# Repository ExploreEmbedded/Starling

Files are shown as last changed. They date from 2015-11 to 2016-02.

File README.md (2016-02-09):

# Starling

Starling is live on CrowdSupply, back us and help this open-source project get to life :)

https://www.crowdsupply.com/explore-embedded/starling 

Starling, aims to be a modular Wifi connected hackable LED Display board. It can be used out of the box to display text messages and custom characters. It can be used from anywhere you're. It should also be able to expand and display messages from web; sports, schedules, social network notifications, whether data, news and anything else you want. The display should be able to expand without changes in the software. The display blocks can be added or removed on the fly 

Front view

For more details do visit the product wiki page.

http://exploreembedded.com/wiki/Starling:_A_simple_internet_connected_modular_led_display.

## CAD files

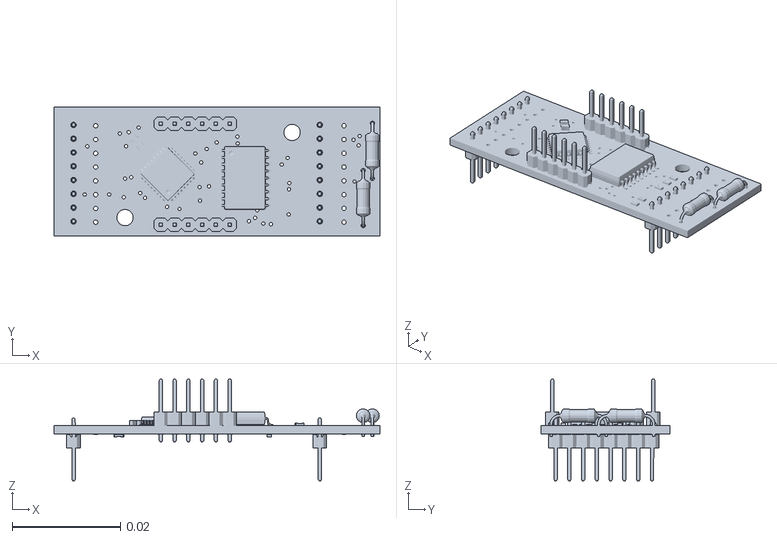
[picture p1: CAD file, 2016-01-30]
Electronics/Starling Matrix PCB v0.2/Starling_V1.stl
0.0601 x 0.0238 x 0.0188

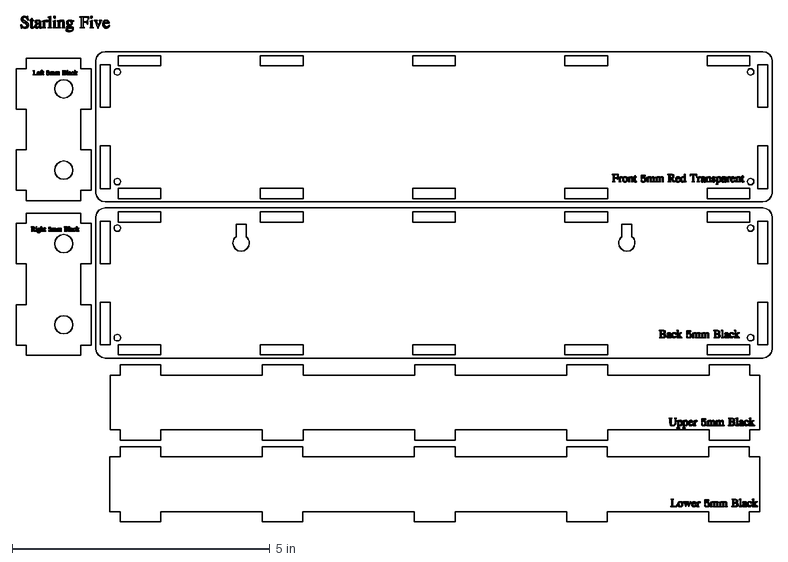
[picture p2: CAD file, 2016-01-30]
Mechanical Design/Starling Five/Starling Five.dxf
14.7 x 9.80 in

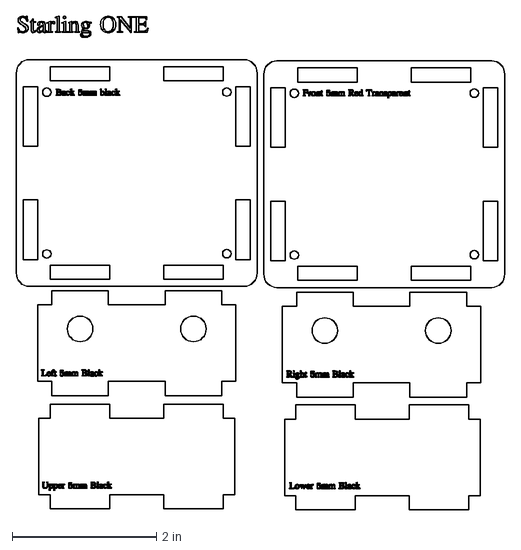
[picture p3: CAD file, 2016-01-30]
Mechanical Design/Starling ONE/Starling ONE.dxf
6.78 x 6.86 in

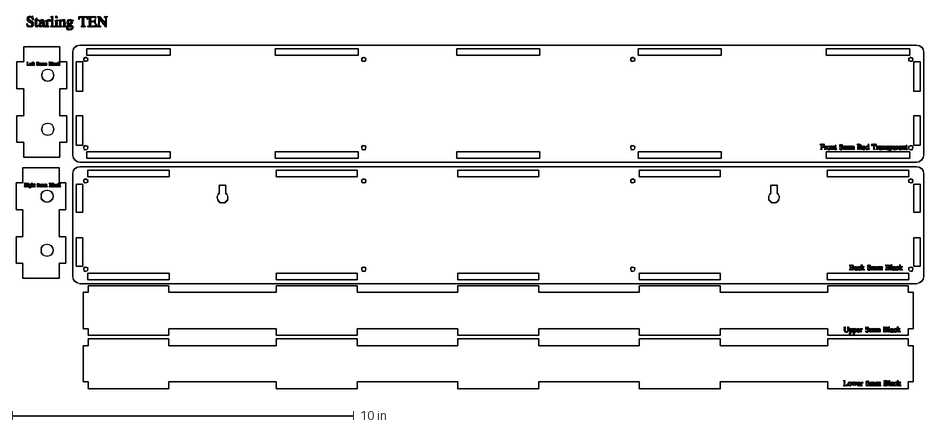
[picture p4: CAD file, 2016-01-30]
Mechanical Design/Starling TEN/Starling TEN.dxf
26.6 x 10.9 in

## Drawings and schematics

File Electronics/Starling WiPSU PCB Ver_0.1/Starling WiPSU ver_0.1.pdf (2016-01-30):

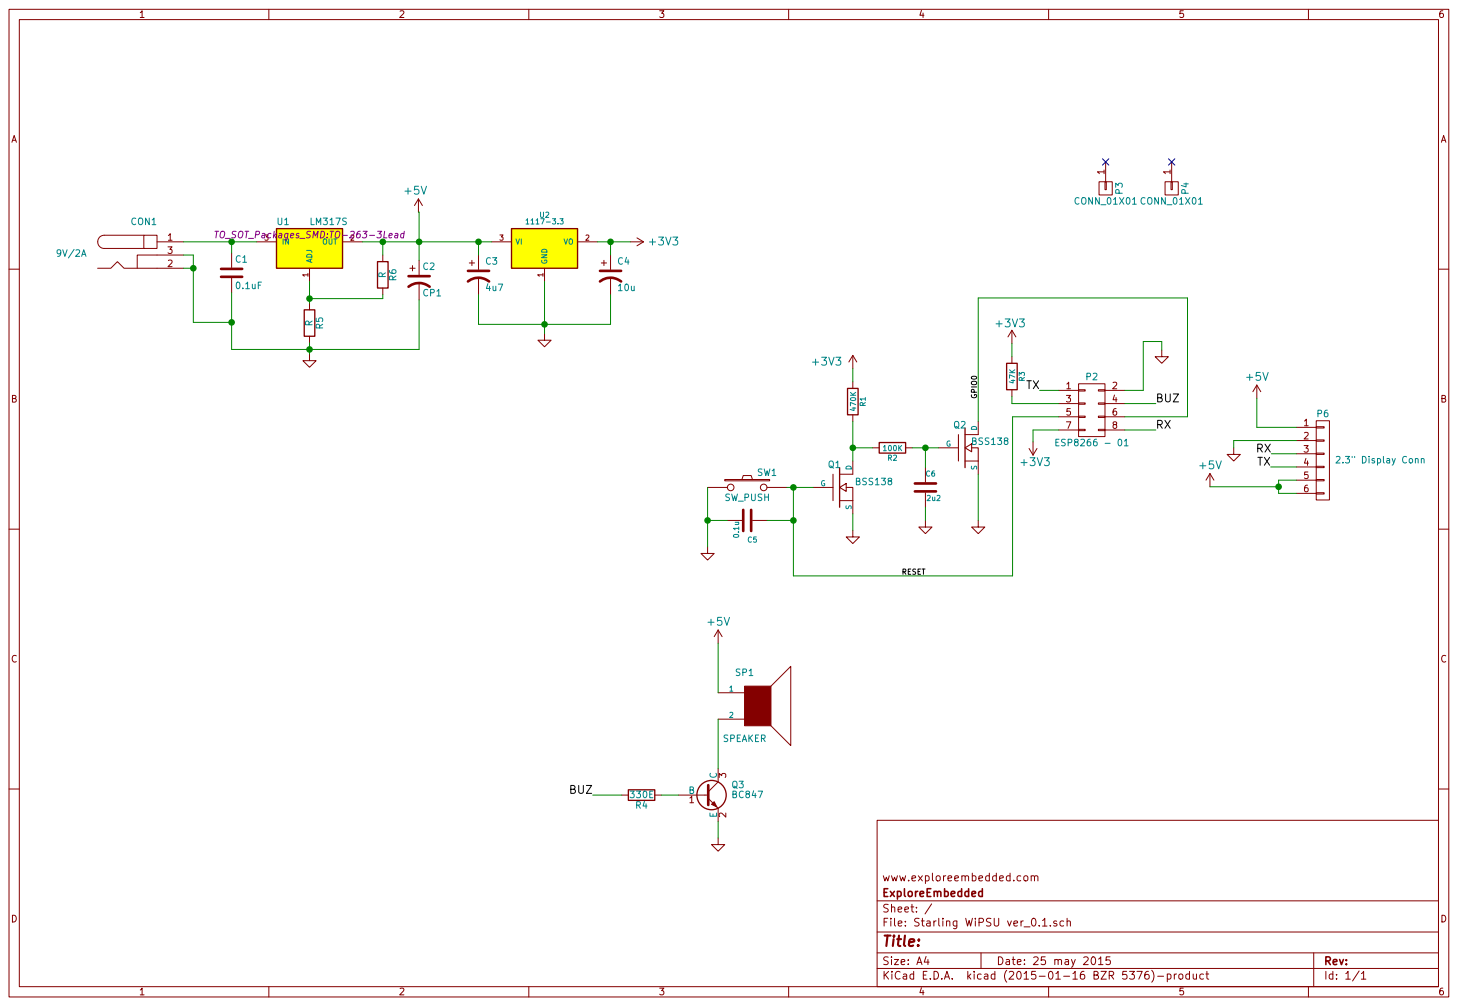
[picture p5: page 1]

www.exploreembedded.com
File: Starling WiPSU ver_0.1.sch Sheet: / ExploreEmbedded

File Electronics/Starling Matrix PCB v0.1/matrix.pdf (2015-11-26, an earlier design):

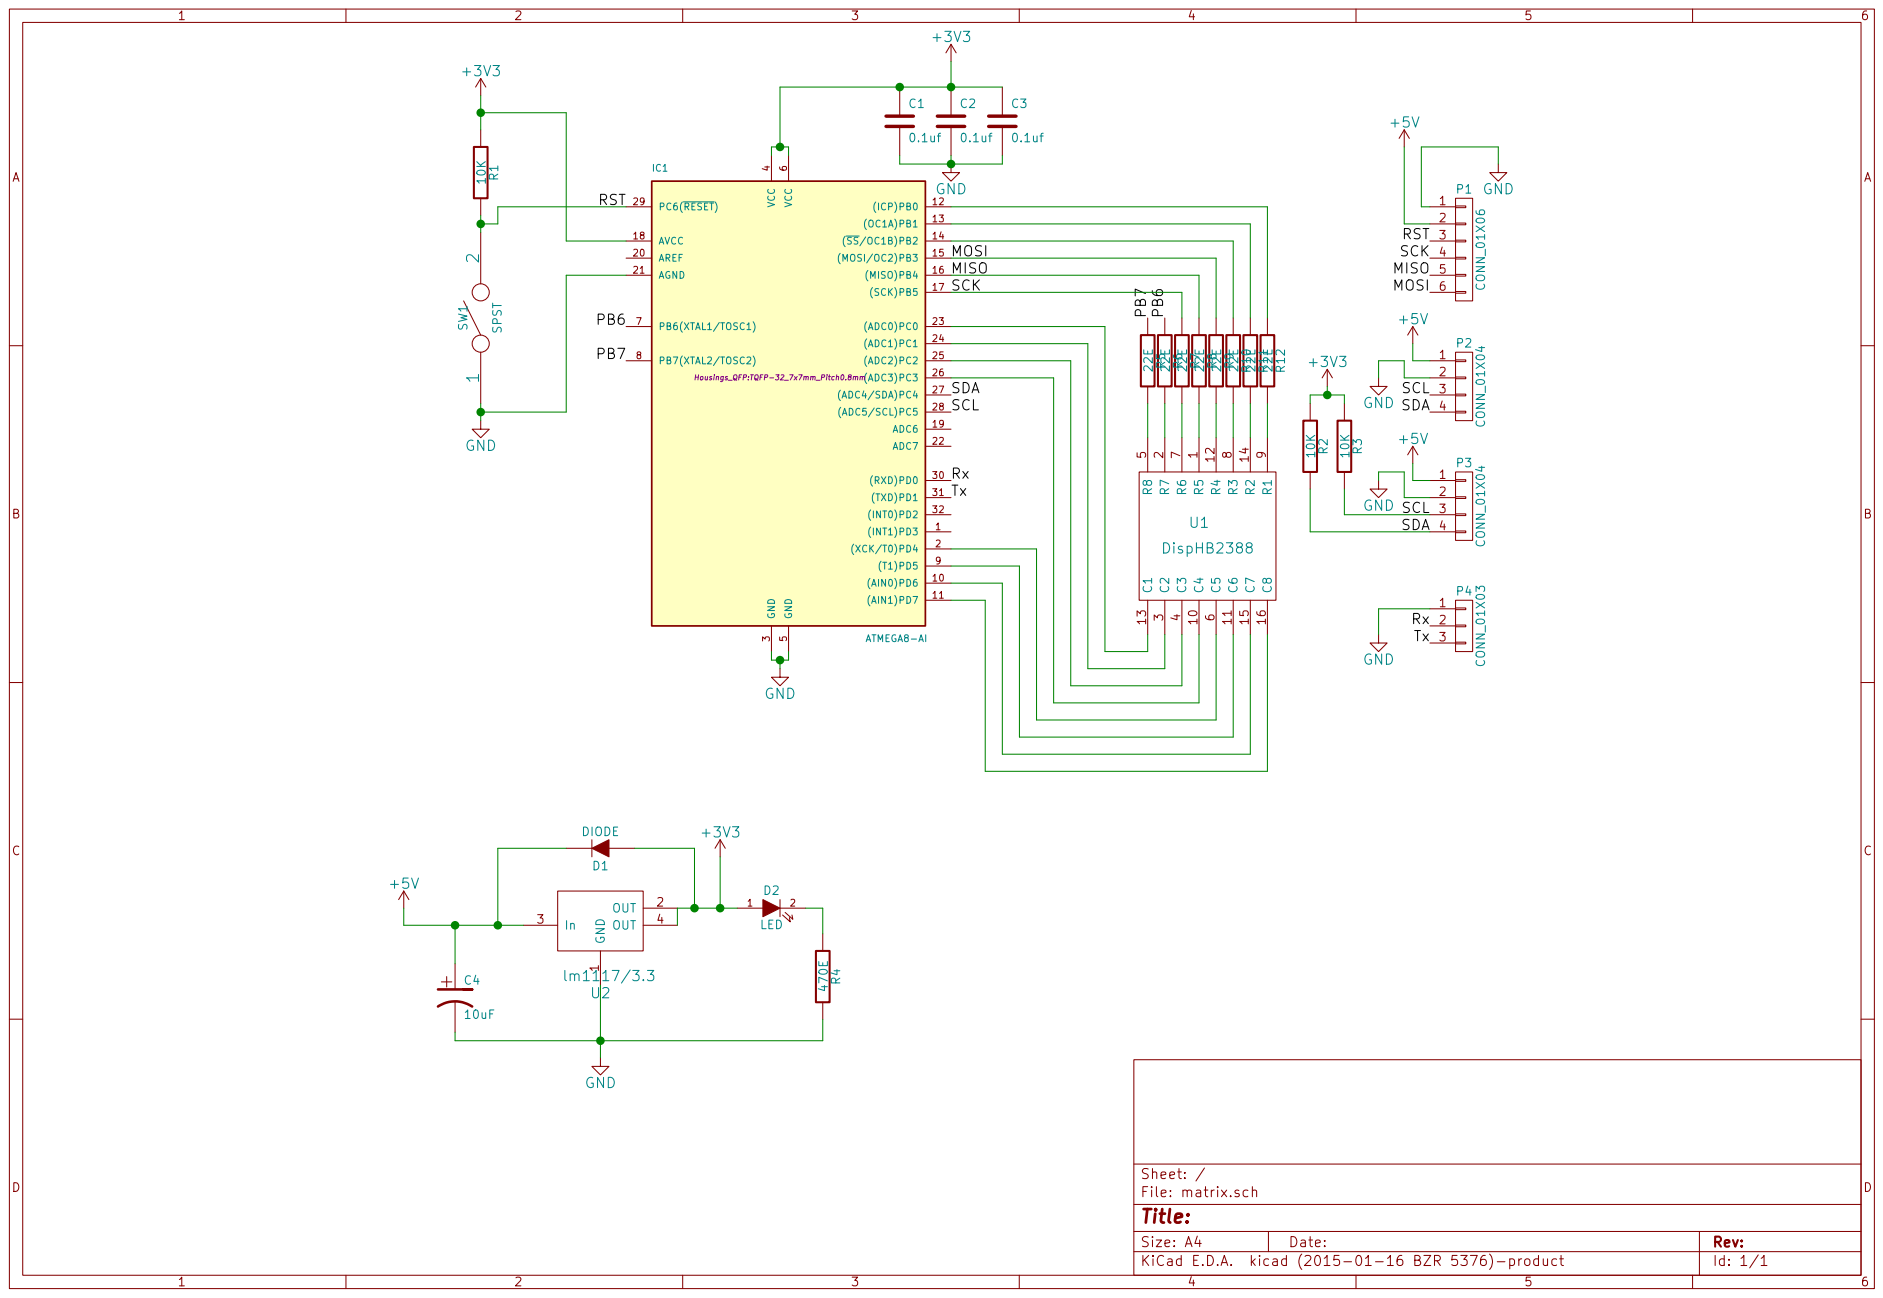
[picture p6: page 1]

Id: 1/1 Title: File: matrix.sch Sheet: /

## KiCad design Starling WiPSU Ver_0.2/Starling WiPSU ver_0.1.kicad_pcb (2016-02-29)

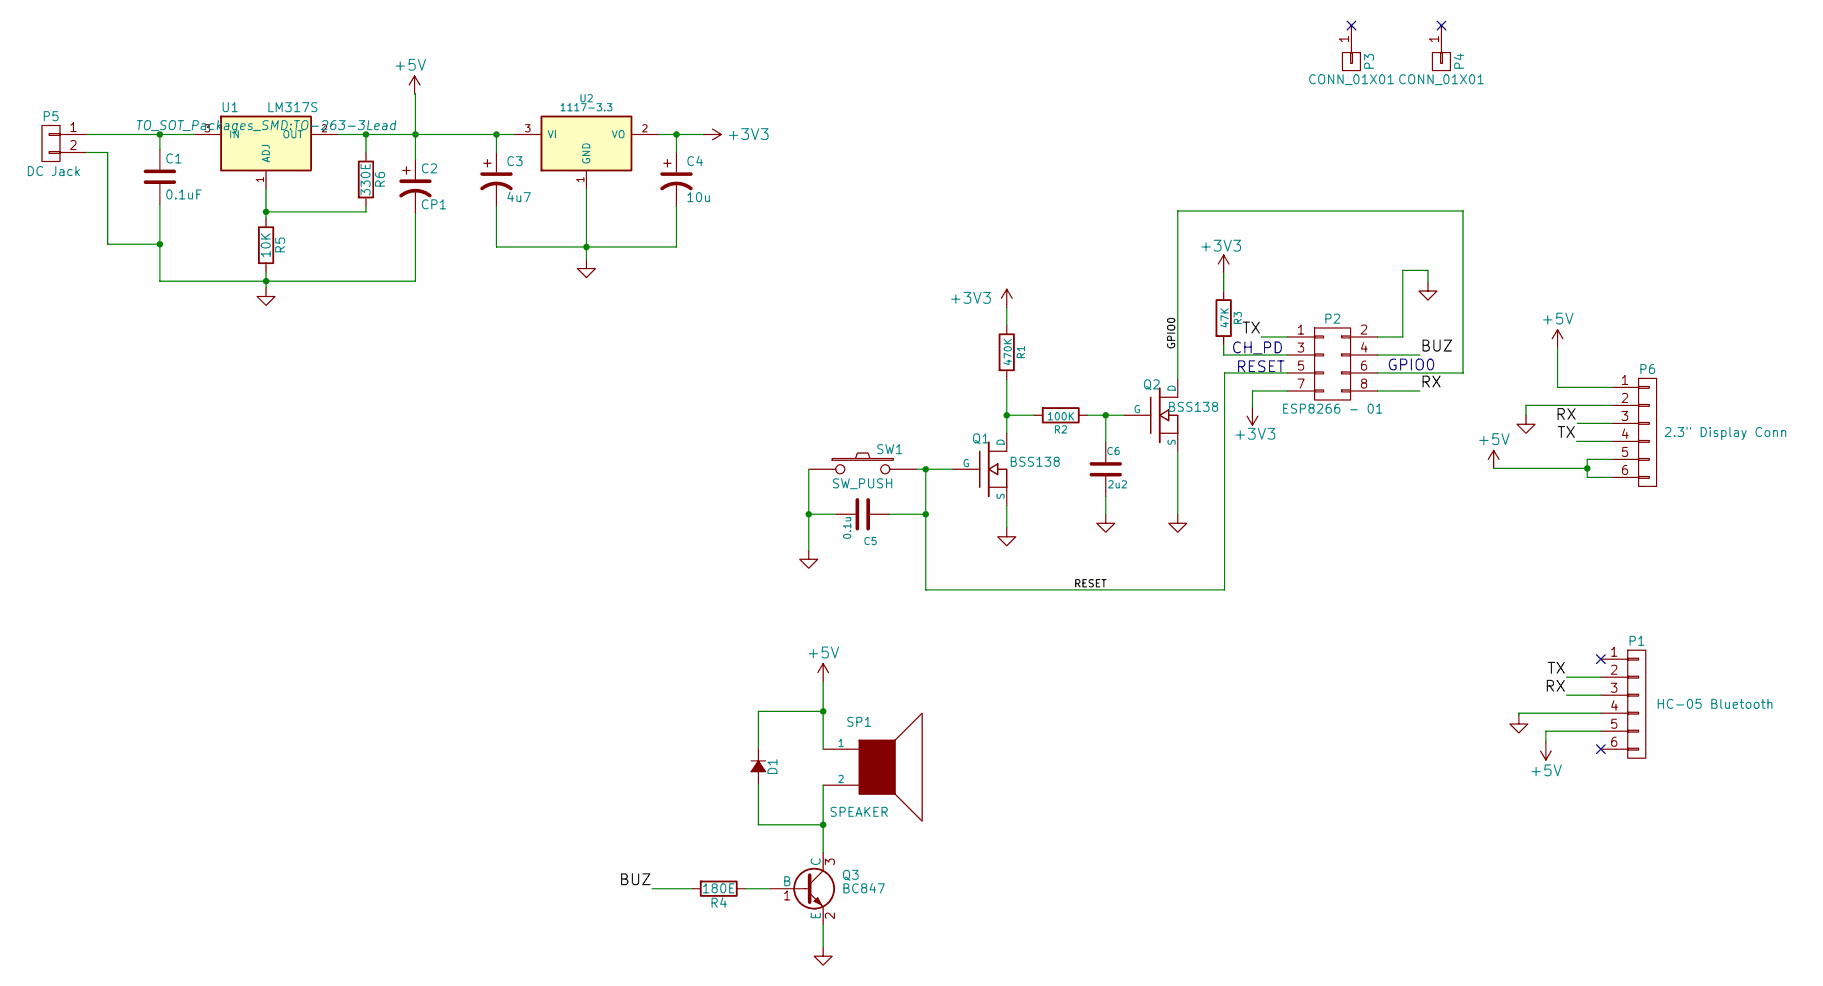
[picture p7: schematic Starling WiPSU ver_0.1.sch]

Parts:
C1: 0.1uF; C_0603
C2: CP1; TantalC_SizeA_EIA-3216_Wave
C3: 4u7; TantalC_SizeA_EIA-3216_Wave
C4: 10u; TantalC_SizeA_EIA-3216_Wave
C5: 0.1u; C_0603
C6: 2u2; C_0603
D1: D_Small; SOD-123
P1: HC-05 Bluetooth; Pin_Header_Straight_1x06
P2: ESP8266 - 01; ESP-01
P3, P4: CONN_01X01; M3_mounting
P5: DC Jack; Pin_Header_Straight_1x02
P6: 2.3\" Display Conn; Pin_Header_Straight_1x06
Q1, Q2: BSS138; SOT23-3
Q3: BC847; SOT-23
R1: 470K; R_0603
R2: 100K; R_0603
R3: 47K; R_0603
R4: 180E; R_0603
R5: 10K; R_0603
R6: 330E; R_0603
SP1: SPEAKER; Buzze_SMD
SW1: SW_PUSH; smd_push
U1: LM317S; TO-263-3Lead
U2: 1117-3.3; SOT-223

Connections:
+3V3: C4.1, P2.7, R1.1, R3.1, U2.2 (VO)
+5V: C2.1, C3.1, D1.1 (K), P1.5, P6.1, P6.5, P6.6, R6.1, SP1.1, U1.2 (OUT), U2.3 (VI)
/BUZ: P2.4, R4.2
/GPIO0: P2.6, Q2.D
/RESET: C5.1, P2.5, Q1.G, SW1.2
/RX: P1.3, P2.8, P6.3
/TX: P1.2, P2.1, P6.4
GND: C1.2, C2.2, C3.2, C4.2, C5.2, C6.2, P1.4, P2.2, P5.2, P6.2, Q1.S, Q2.S, Q3.2 (E), R5.2, SW1.1, U2.1 (GND)
unnamed: C1.1, P5.1, U1.3 (IN)
unnamed: C6.1, Q2.G, R2.1
unnamed: D1.2 (A), Q3.3 (C), SP1.2
unnamed: P2.3, R3.2
unnamed: Q1.D, R1.2, R2.2
unnamed: Q3.1 (B), R4.1
unnamed: R5.1, R6.2, U1.1 (ADJ)

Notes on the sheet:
RESET
GPIO0
CH_PD

Board: 2 copper layers, 26 parts (11 on the bottom side), 15 nets, no tracks yet.

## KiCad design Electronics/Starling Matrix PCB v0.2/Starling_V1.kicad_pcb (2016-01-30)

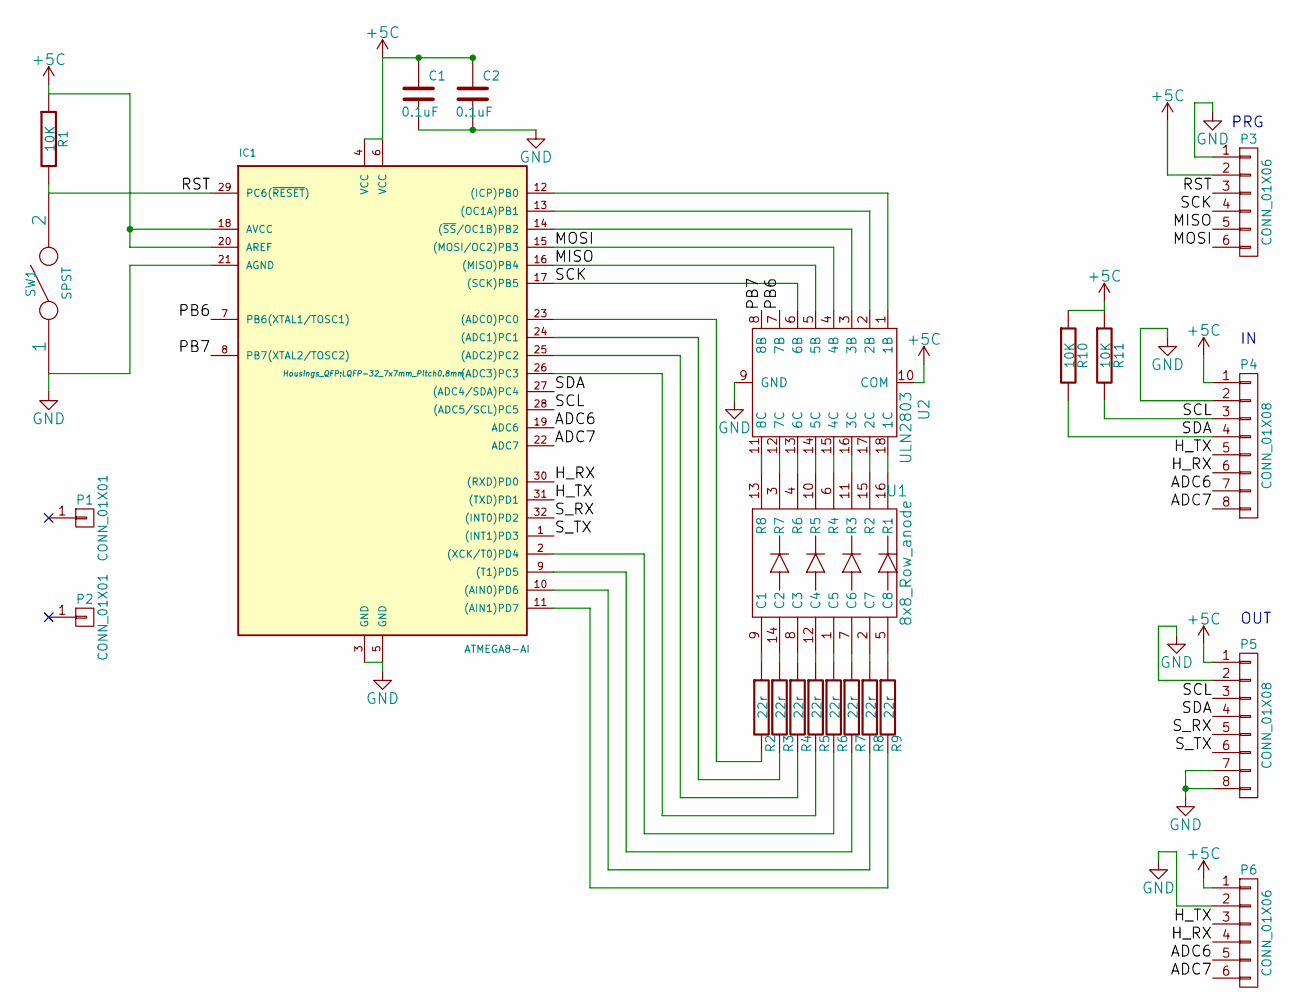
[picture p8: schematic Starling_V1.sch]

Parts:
C1, C2: 0.1uF; C_0603
IC1: ATMEGA8-AI; LQFP-32_7x7mm_Pitch0.8mm
P1, P2: CONN_01X01; M3_mounting
P3, P6: CONN_01X06; Pin_Header_Straight_1x06
P4, P5: CONN_01X08; Pin_Header_Straight_1x08
R1: 10K; R_0603
R2, R3, R4, R5, R6, R7, R8, R9: 22r; R_0603
R10, R11: 10K; Resistor_Horizontal_RM10mm
SW1: SPST; smd_push
U1: 8x8_Row_anode; 8X8_matrix_2.3inch
U2: ULN2803; SOIC-18_7.5x11.6mm_Pitch1.27mm

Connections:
+5C: C1.1, C2.1, IC1.4 (VCC), IC1.6 (VCC), IC1.18 (AVCC), IC1.20 (AREF), P3.2, P4.1, P5.1, P6.1, R1.1, R10.1, R11.1, U2.10 (COM)
/ADC6: IC1.19 (ADC6), P4.7, P6.5
/ADC7: IC1.22 (ADC7), P4.8, P6.6
/H_RX: IC1.30 ((RXD)PD0), P4.6, P6.4
/H_TX: IC1.31 ((TXD)PD1), P4.5, P6.3
/MISO: IC1.16 ((MISO)PB4), P3.5, U2.5 (5B)
/MOSI: IC1.15 ((MOSI/OC2)PB3), P3.6, U2.4 (4B)
/PB6: IC1.7 (PB6(XTAL1/TOSC1)), U2.7 (7B)
/PB7: IC1.8 (PB7(XTAL2/TOSC2)), U2.8 (8B)
/RST: IC1.29 (PC6(~RESET~)), P3.3, R1.2, SW1.2
/SCK: IC1.17 ((SCK)PB5), P3.4, U2.6 (6B)
/SCL: IC1.28 ((ADC5/SCL)PC5), P4.3, P5.3, R11.2
/SDA: IC1.27 ((ADC4/SDA)PC4), P4.4, P5.4, R10.2
/S_RX: IC1.32 ((INT0)PD2), P5.5
/S_TX: IC1.1 ((INT1)PD3), P5.6
GND: C1.2, C2.2, IC1.3 (GND), IC1.5 (GND), IC1.21 (AGND), P3.1, P4.2, P5.2, P5.7, P5.8, P6.2, SW1.1, U2.9 (GND)
unnamed: IC1.2 ((XCK/T0)PD4), R6.2
unnamed: IC1.9 ((T1)PD5), R7.2
unnamed: IC1.10 ((AIN0)PD6), R8.2
unnamed: IC1.11 ((AIN1)PD7), R9.2
unnamed: IC1.12 ((ICP)PB0), U2.1 (1B)
unnamed: IC1.13 ((OC1A)PB1), U2.2 (2B)
unnamed: IC1.14 ((~SS~/OC1B)PB2), U2.3 (3B)
unnamed: IC1.23 ((ADC0)PC0), R2.2
unnamed: IC1.24 ((ADC1)PC1), R3.2
unnamed: IC1.25 ((ADC2)PC2), R4.2
unnamed: IC1.26 ((ADC3)PC3), R5.2
unnamed: R2.1, U1.9 (C1)
unnamed: R3.1, U1.14 (C2)
unnamed: R4.1, U1.8 (C3)
unnamed: R5.1, U1.12 (C4)
unnamed: R6.1, U1.1 (C5)
unnamed: R7.1, U1.7 (C6)
unnamed: R8.1, U1.2 (C7)
unnamed: R9.1, U1.5 (C8)
unnamed: U1.3 (R7), U2.12 (7C)
unnamed: U1.4 (R6), U2.13 (6C)
unnamed: U1.6 (R4), U2.15 (4C)
unnamed: U1.10 (R5), U2.14 (5C)
unnamed: U1.11 (R3), U2.16 (3C)
unnamed: U1.13 (R8), U2.11 (8C)
unnamed: U1.15 (R2), U2.17 (2C)
unnamed: U1.16 (R1), U2.18 (1C)

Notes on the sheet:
PRG
OUT

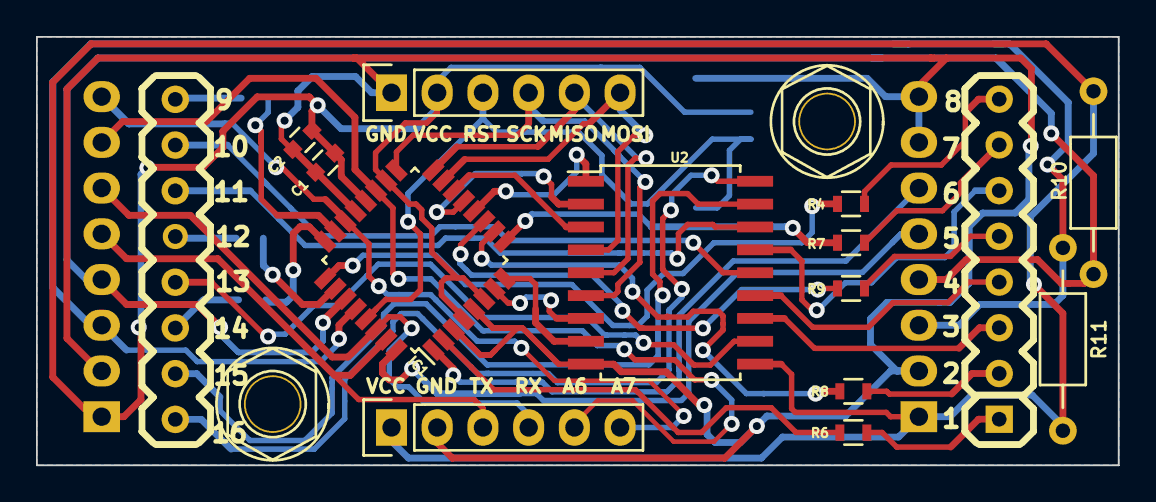
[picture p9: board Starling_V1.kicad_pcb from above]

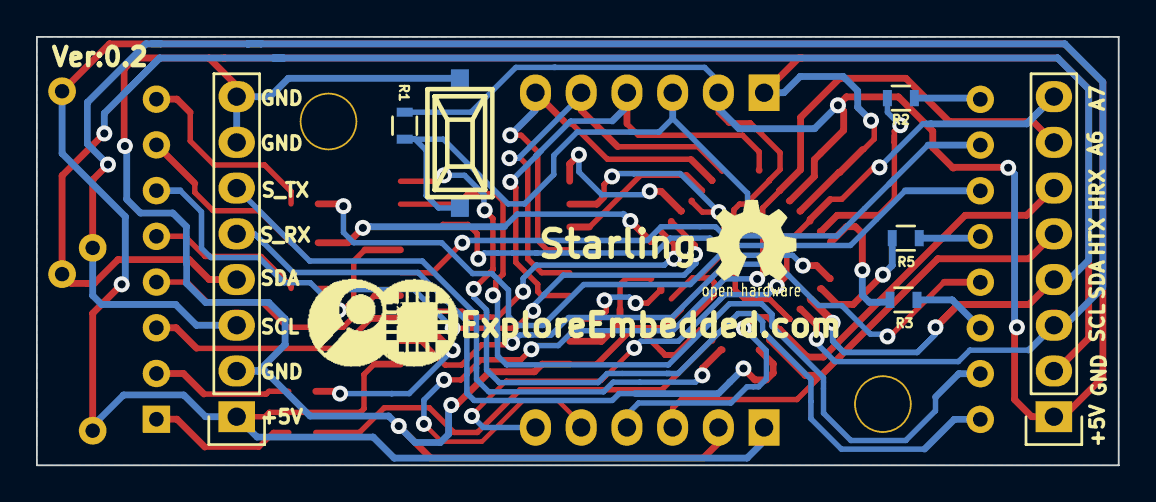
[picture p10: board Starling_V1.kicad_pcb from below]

Board: 2 copper layers, 60.1 x 23.8 mm, 24 parts (8 on the bottom side), 43 nets.

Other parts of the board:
LOGO: LOGO (2)

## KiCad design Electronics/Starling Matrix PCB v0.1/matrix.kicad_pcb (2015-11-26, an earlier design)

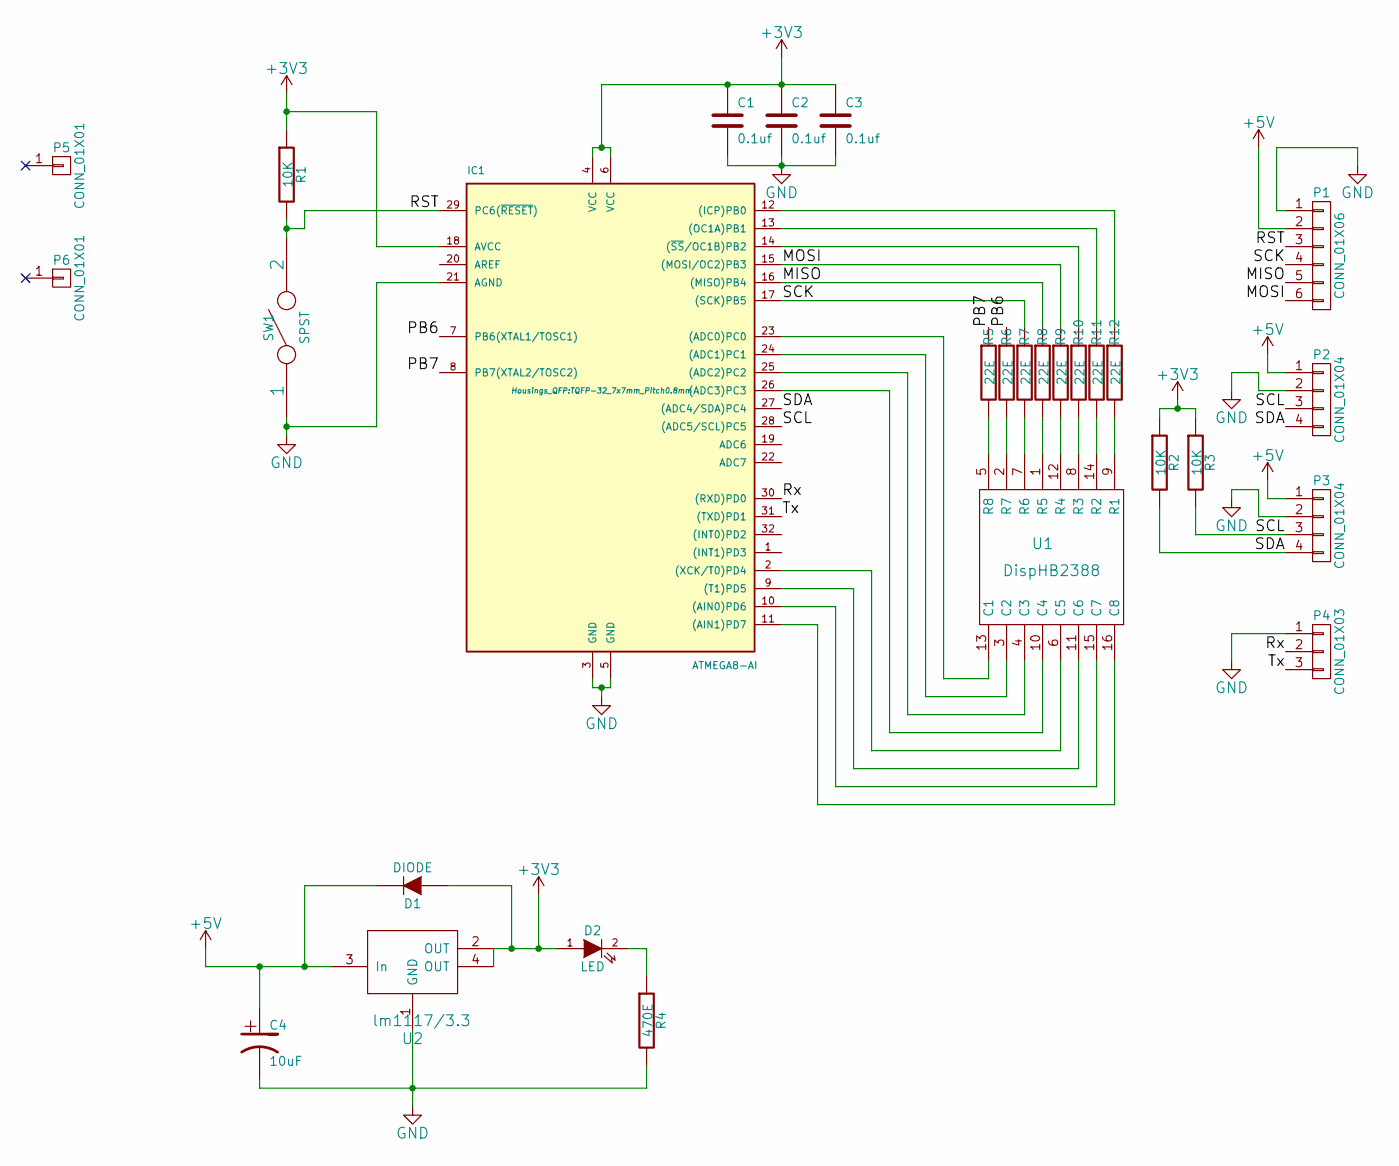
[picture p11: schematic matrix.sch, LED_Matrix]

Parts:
C1, C2, C3: 0.1uf; C_0603_HandSoldering
C4: 10uF; TantalC_SizeA_EIA-3216_Wave
D1: DIODE; SMA_Standard
D2: LED; LED-0603
IC1: ATMEGA8-AI; TQFP-32_7x7mm_Pitch0.8mm
P1: CONN_01X06; Pin_Header_Straight_1x06
P2, P3: CONN_01X04; matrix_connector
P4: CONN_01X03; Pin_Header_Straight_1x03
P5, P6: CONN_01X01; 1pin
R1, R2, R3: 10K; R_0603_HandSoldering
R4: 470E; R_0603_HandSoldering
R5, R6, R7, R8, R9, R10, R11, R12: 22E; R_0603_HandSoldering
SW1: SPST; smd_push
U1: DispHB2388; 8x8dot matrix
U2: lm1117/3.3; lm117_SOT-223

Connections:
+3V3: C1.1, C2.1, C3.1, D1.1 (A), D2.1 (A), IC1.4 (VCC), IC1.6 (VCC), IC1.18 (AVCC), R1.1, R2.1, R3.1, U2.2 (OUT), U2.4 (OUT)
+5V: C4.1, D1.2 (K), P1.2, P2.1, P3.1, U2.3 (In)
/MISO: IC1.16 ((MISO)PB4), P1.5, R8.1
/MOSI: IC1.15 ((MOSI/OC2)PB3), P1.6, R9.1
/PB6: IC1.7 (PB6(XTAL1/TOSC1)), R6.1
/PB7: IC1.8 (PB7(XTAL2/TOSC2)), R5.1
/RST: IC1.29 (PC6(~RESET~)), P1.3, R1.2, SW1.2
/Rx: IC1.30 ((RXD)PD0), P4.2
/SCK: IC1.17 ((SCK)PB5), P1.4, R7.1
/SCL: IC1.28 ((ADC5/SCL)PC5), P2.3, P3.3, R3.2
/SDA: IC1.27 ((ADC4/SDA)PC4), P2.4, P3.4, R2.2
/Tx: IC1.31 ((TXD)PD1), P4.3
GND: C1.2, C2.2, C3.2, C4.2, IC1.3 (GND), IC1.5 (GND), IC1.21 (AGND), P1.1, P2.2, P3.2, P4.1, R4.2, SW1.1, U2.1 (GND)
unnamed: D2.2 (K), R4.1
unnamed: IC1.2 ((XCK/T0)PD4), U1.6 (C5)
unnamed: IC1.9 ((T1)PD5), U1.11 (C6)
unnamed: IC1.10 ((AIN0)PD6), U1.15 (C7)
unnamed: IC1.11 ((AIN1)PD7), U1.16 (C8)
unnamed: IC1.12 ((ICP)PB0), R12.1
unnamed: IC1.13 ((OC1A)PB1), R11.1
unnamed: IC1.14 ((~SS~/OC1B)PB2), R10.1
unnamed: IC1.23 ((ADC0)PC0), U1.13 (C1)
unnamed: IC1.24 ((ADC1)PC1), U1.3 (C2)
unnamed: IC1.25 ((ADC2)PC2), U1.4 (C3)
unnamed: IC1.26 ((ADC3)PC3), U1.10 (C4)
unnamed: R5.2, U1.5 (R8)
unnamed: R6.2, U1.2 (R7)
unnamed: R7.2, U1.7 (R6)
unnamed: R8.2, U1.1 (R5)
unnamed: R9.2, U1.12 (R4)
unnamed: R10.2, U1.8 (R3)
unnamed: R11.2, U1.14 (R2)
unnamed: R12.2, U1.9 (R1)

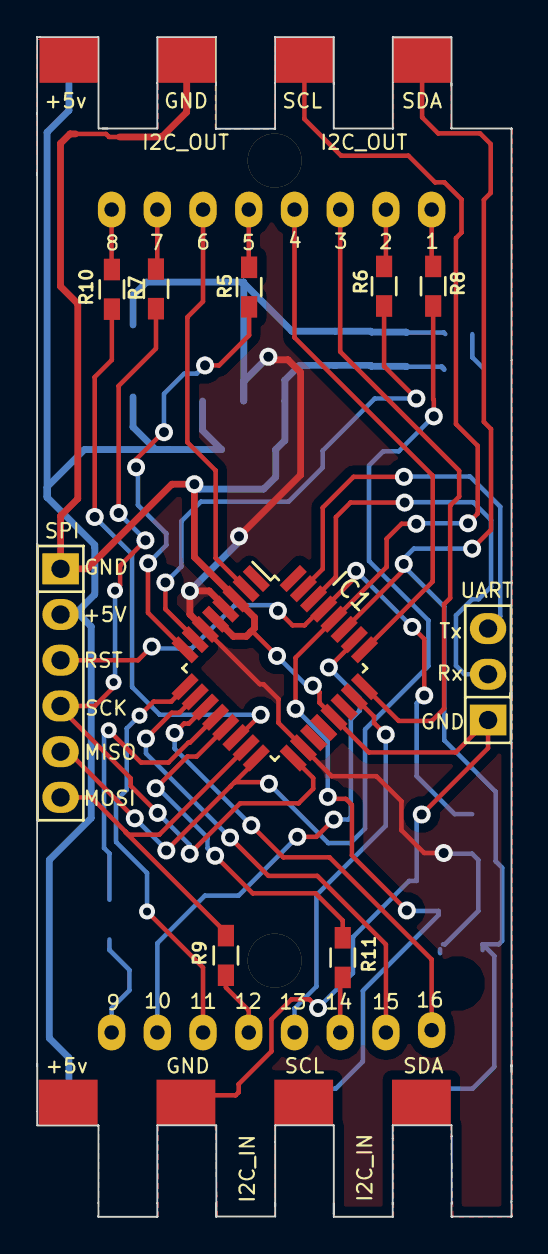
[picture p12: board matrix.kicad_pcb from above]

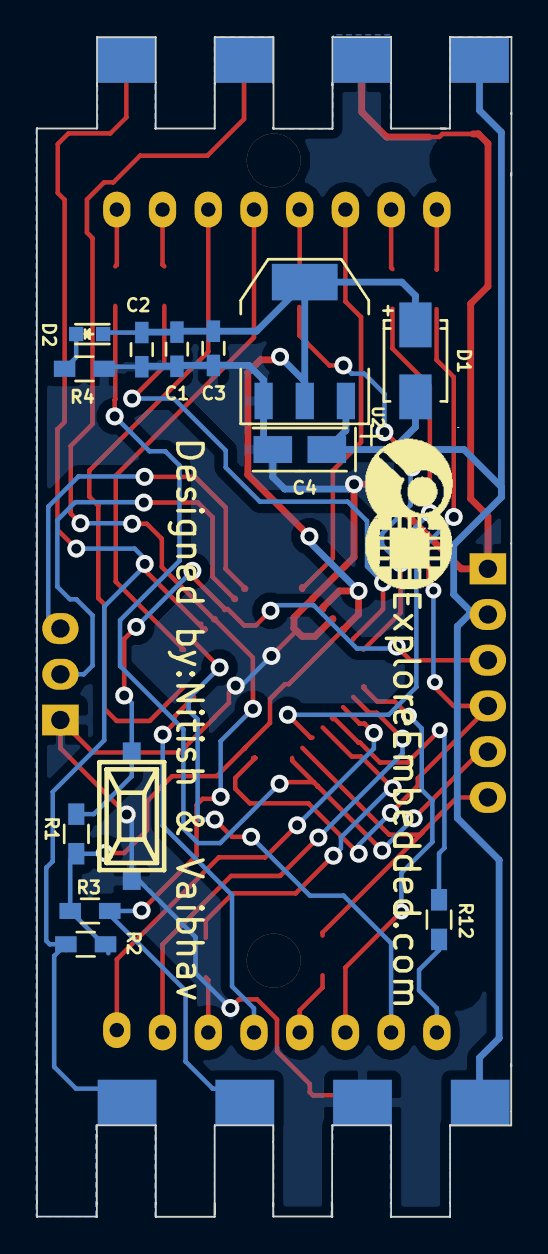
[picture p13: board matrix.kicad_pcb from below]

Board: 2 copper layers, 26.4 x 65.6 mm, 29 parts (14 on the bottom side), 33 nets.

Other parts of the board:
LOGO: LOGO (2)

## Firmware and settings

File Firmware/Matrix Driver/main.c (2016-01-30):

#include <avr\io.h>
#include<avr/pgmspace.h>
#include<avr/interrupt.h>
#include <string.h>
#include "delay.h"
#include"sw_uart.h"
#include "uart.h"
#include "config.h"
#include "twi.h"
#include "adc.h"



//#define SIMULATION 0x00  //0xff for Simulation, 0x00 for real Time
#define MaxSegments 15
#define MaxColPerSegment 8

uint8_t NumberOfSegments = MaxSegments;

//#define EnableBlankSpaces

#ifdef SMALLDISPLAY
#define SIMULATION 0xff
#else
#define SIMULATION 0x00
#endif

//uint8_t pattern[16] = {0xc3,0x91,0x24,0x20,0x20,0x24,0x91,0xc3};
uint8_t pattern[16] = {0x3c,0x6e,0xdb,0xdf,0xdf,0xdb,0x6e,0x3c};    //pattern for animation
uint8_t colSelection[8] = {1,2,4,8,16,32,64,128}; /* Select One column at atime */


volatile uint8_t MyDeviceId = 0x30,NextDeviceId = 0x32,IdConfirmed=0,sendNewIdCount = 0;
volatile uint16_t debounceCount = 0;
volatile uint8_t TimeTick = 0;
uint8_t deviceType = MASTER;
uint8_t state = E_Init;
extern const uint8_t Font[][8];

volatile uint8_t NewMsgLength = 0;
volatile uint8_t NewMsgReceived = 0;
uint8_t isrBuffer[MSG_SIZE];
volatile uint8_t inputBuffer[MSG_SIZE]={"hello"};
uint8_t msgBuffer[MSG_SIZE] = "ABCDEFGHIJ";
uint8_t FrameBuffer[MAX_DEVICES*FONT_SIZE];

volatile uint8_t isrColIndex;
uint8_t MsgLength = 10;



void BuildFrame(uint8_t *msgPtr);
void GetFont(uint8_t ch,uint8_t *font);
void StartDisplayTimer();
void ScrollString(char *ptr_msgPointer);
void DisplayString(char *ptr_msgPointer);
void TWI_ScrollFrame(void);




#define DELAY_TIME 75

int main()
{
    int16_t length=0,adc_value1,adc_value2;
    uint8_t i;
    DELAY_ms(100);
    ADC_Init();
    TIMSK = 0x00;
    DDRB= 0xff;
    DDRC = 0xff;
    DDRD = 0xff;
    PORTC = 0xff;



    while(1)
    {

        switch(state)
        {
        case E_Init:
            DELAY_ms(200);
            ADC_Init();
            adc_value1 = ADC_GetAdcValue(6);
            adc_value2 = ADC_GetAdcValue(7);

           // UART_Init(BAUD_RATE);
          //  sw_uart_init();
            StartDisplayTimer();

            sei();
          //  GetFont('1',pattern);

            while(1);
            MsgLength = strlen(inputBuffer);


            if( (adc_value1 >= 600) && (adc_value2 >= 600) )
            {
                deviceType = MASTER;
            }
            else
            {
                deviceType = SLAVE;
            }

            state = E_StartArbitration;
            break;

        case E_StartArbitration:

            GetFont(((MyDeviceId-0x30)/2)+0x30,pattern);
            if(deviceType == MASTER)
            {
                DELAY_ms(500);

                TCCR2 = 0x00;
                TIMSK = 0x01;
                TWI_init_master();
                state = E_MasterDisp;
            }
            else
            {
                if(IdConfirmed == 1)
                {
                    DELAY_ms(250);

                    TCCR2 = 0x00;
                    TIMSK = 0x01;
                    DisableHwUartComm();
                    TWI_init_slave(MyDeviceId);
                    state = E_SlaveDisp;
                }
            }
            break;


        case E_MasterDisp:

            if(NewMsgReceived!=0)
            {

                MsgLength = NewMsgLength;
                NewMsgReceived = 0;
                NewMsgLength = 0;
            }

            strcpy(msgBuffer,inputBuffer);

            if(MsgLength > NumberOfSegments)
            {
                ScrollString(msgBuffer);
            }
            else
            {

                DisplayString(msgBuffer);
            }

            break;

        case E_SlaveDisp:

            TWI_Receive_Frame(FrameBuffer);
            for(i=0;i<8;i++)
                pattern[i] = FrameBuffer[i];

            break;
        }
    }
}



void BuildFrame(uint8_t *msgPtr)
{
    uint8_t i,endOfFrame=0;

    for(i=0;i<(MAX_DEVICES);i++)
    {

        if(endOfFrame == 0)
        {
            if(msgPtr[i] == 0)
            {
                endOfFrame = 1;
            }
        }


        if(endOfFrame == 0)
        {
            GetFont(msgPtr[i],(FrameBuffer+(i*8)));
        }
        else
        {
            GetFont(' ',(FrameBuffer+(i*8)));
        }
    }
}



void DisplayString(char *ptr_msgPointer)
{
    int i,j;
    uint8_t activeStatus = 1;
    NumberOfSegments = 1;
    BuildFrame(ptr_msgPointer);

    for(i=0;activeStatus;i++)
    {
        if(i==0)
        {
            for(j=0;j<8;j++)
                pattern[j] = FrameBuffer[j];
        }
        else
        {
            TWI_start(); // Function to send start condition

            activeStatus = TWI_write_address(i*2+0x30); // Function to write address and data direction bit(write) on SDA
            if(activeStatus)
            {
                NumberOfSegments++;
                for(j=0;j<8;j++)
                {
                    TWI_write_data(FrameBuffer[i*8+j]);      // Function to write data in slave
                    //   UART_TxChar(' ');
                    // UART_TxHexNumber(i,2);      // Function to write data in slave
                }
            }
            TWI_stop(); // Function to send stop condition
        }
    }
}







void ScrollString(char *ptr_msgPointer)
{
    unsigned char i,len;

    len = NumberOfSegments+ MsgLength;
    ptr_msgPointer[len+1] = 0;
    ptr_msgPointer[len] = ' ';
    for(i=len-1;i>(NumberOfSegments-1);i--)
    {
        ptr_msgPointer[i] = ptr_msgPointer[i-(NumberOfSegments)];
    }
    for(i=0;i<(NumberOfSegments);i++)
    {
        ptr_msgPointer[i] = ' ';
    }

    for(i=0;(ptr_msgPointer[i]) && (NewMsgReceived==0);i++)
    {
        /* Loop to display the complete string, each time N chars are displayed and
                pointer is incremented to point to next char */

        BuildFrame(ptr_msgPointer+i);

        TWI_ScrollFrame();
        /*   if(NewMsgReceived == 1)
            {
                BuildFrame(ptr_msgPointer+i+1);
                TWI_HorizontalScrollFrame(0);
            } */
    }
}


void TWI_ScrollFrame(void)
{
    uint8_t segindex=0,i,j;
    uint8_t str_Ptr[8];
    uint8_t activeStatus = 1;


    while((segindex<8) && (NewMsgReceived==0))
    {
        activeStatus = 1;
        NumberOfSegments = 1;
        for(i=0; (activeStatus) && (NewMsgReceived==0);i++)
        {


            for(j=0;j<MaxColPerSegment;j++)
            {

                str_Ptr[j] = FrameBuffer[(i*8)+j+segindex];
            }



            if(i==0)
            {
                for(j=0;j<MaxColPerSegment;j++)
                {
                    pattern[j] = str_Ptr[j];
                }
            }
            else
            {

                activeStatus = TWI_start(); // Function to send start condition

                if(activeStatus)
                {

                    activeStatus = TWI_write_address(i*2+0x30); // Function to write address and data direction bit(write) on SDA

                    if(activeStatus)
                    {

                        NumberOfSegments++;
                        for(j=0;j<8;j++)
                        {
                            TWI_write_data(str_Ptr[j]);      // Function to write data in slave
                        }
                    }
                }

                TWI_stop(); // Function to send stop condition
            }
        }

        for(i=NumberOfSegments;i<MAX_DEVICES;i++)
            DELAY_ms(SCROLL_DELAY_MS);
        segindex++;
    }
}










void GetFont(uint8_t ch,uint8_t *font)
{
    uint8_t i=0;
    uint8_t *ptr;
    ch = ch-0x20;
    ptr =(uint8_t*)Font[ch];

    for(i=0;i<8;i++)
    {
        font[i] = pgm_read_byte(ptr+i);
    }
}


void StartDisplayTimer()
{
    TCCR0 = 0X01;
    TCNT0 = 253;
    TIMSK|=0x01 ;
}

ISR (TIMER0_OVF_vect)
{
    char val = (colSelection[isrColIndex]);

    PORTB = 0x00;

    PORTC = (PORTC & 0xF0)| (val & 0x0F);   // Higher four Rows/Cols are connected to PC4-PC7
    PORTD = (PORTD & 0x0F) | (val & 0xF0);  // Lower four Rows/Cols are connected to PD0-PD3

    PORTB = pattern[isrColIndex];

    isrColIndex++;
    if(isrColIndex == 8)
    {
        isrColIndex = 0x00;

        if(state == E_StartArbitration)
        {
            if(sendNewIdCount == 10)
            {
                NextDevice_SendData(NextDeviceId);
                sendNewIdCount = 0;
            }
            else
            {
                sendNewIdCount++;
            }
        }
    }
    TimeTick++;
}



void handleUartData()
{
    char ch;
    static uint8_t inputBufferIndex = 0;
    ch = UDR;
    if(deviceType == MASTER)
    {

        if((ch == '\n') || (ch == '\r'))
        {
            if(inputBufferIndex > 0)
            {
                for(NewMsgLength=0;NewMsgLength<inputBufferIndex;NewMsgLength++)
                {
                    inputBuffer[NewMsgLength]= isrBuffer[NewMsgLength];
                }
                inputBuffer[NewMsgLength] = 0;
                NewMsgReceived = 1;
                inputBufferIndex= 0x00;
            }
        }
        else if(inputBufferIndex<(MSG_SIZE-1))
        {
             UDR = ch;
            isrBuffer[inputBufferIndex] = ch;
            inputBufferIndex++;
        }
    }
    else
    {
        if(IdConfirmed == 0)
        {
            if((ch>0x30) && (ch<0x50))
            {
                if(MyDeviceId == ch)
                {
                    if(debounceCount>=100)
                    {
                        IdConfirmed = 1;
                    }
                    else
                    {
                        debounceCount++;
                    }
                }
                else
                {
                    MyDeviceId =  ch;
                    NextDeviceId =  ch + 2; /* Device Ids start form 0x30,0x32---0x42 */
                }
            }
        }
    }
}


ISR (USART_RXC_vect)
{
    handleUartData();
}

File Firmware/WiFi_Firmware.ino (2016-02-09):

#include <ESP8266WiFi.h>          //https://github.com/esp8266/Arduino

//needed for library
#include <DNSServer.h>
#include <ESP8266WebServer.h>
#include <WiFiManager.h>         //https://github.com/tzapu/WiFiManager
#include <WiFiClient.h>
#include <PubSubClient.h>

char* mqttserver = "128.199.72.21"; //change this to your server if required  
char message_buff[300];   // 
char respBuffer[300];
int8_t MQTT_Status;// return status of the mqtt connect

char macString[18] = {0};
char clientName[20] = {0};


WiFiClient wifiClient;
PubSubClient client(mqttserver, 1883, callback, wifiClient); 


char* getMacString()
{
  uint8_t mac[6];
  WiFi.macAddress(mac);
  sprintf(macString, "%02X%02X%02X%02X%02X%02X\0", mac[0],  mac[1], mac[2], mac[3], mac[4], mac[5]);
  return (macString);
}

//Create client name wth mac address

char* getClientName()
{
  uint8_t mac[6];
  WiFi.macAddress(mac);
  sprintf(clientName, "*_%02X%02X%02X%02X%02X%02X\0", mac[0],  mac[1], mac[2], mac[3], mac[4], mac[5]);
  return (clientName);
}

void setup() {

    Serial.begin(9600);
    WiFiManager wifiManager;
    //wifiManager.resetSettings();// Use to clear all Wifi Settings
    wifiManager.autoConnect(getClientName(),"set_pass");
    Serial.println("Connected to Local Network");
}

void loop() {

        MQTT_Status = client.state();
         
         switch(MQTT_Status){
              case -4: Serial.println("Connection timed out"); break;
              case -3: Serial.println("MQTT  connection lost"); break;
              case -2: break;  Serial.println("No internet connection, retrying in 1 min. . .");
              case -1: Serial.println("Client disconnected cleanly"); break;
              case 0: break;
              case 1: Serial.println("Bad Protocol"); break;
              case 2: Serial.println("Bad Client ID"); break;
              case 3: Serial.println("Connection unavailable"); break;
              case 4: Serial.println("Username or Password is incorrect"); break;
              case 5: Serial.println("Unauthorized connection"); break;
          }

        if(MQTT_Status<0)
        {
           //wait for 2 seconds, before trying again
           delay(1000);
           //client name and topic are kept the same. 
           Serial.println("Connecting to Starling Server");
           if(client.connect(getClientName(),"your_username","your_password")) // device id, user id, password
            {
               Serial.println("Connected! Retreiving default message!");
               //client.publish("STAR0001","Starling is flying");
               client.subscribe(getMacString());
               client.publish("master/status", getMacString());
               client.publish("master","Starling is flying"); 
              //client.publish(getMacString(),"Starling is flying");
              // Serial.println("Connected to Starling Server!");           
            }
        }

      client.loop();
    
    
}

void callback(char* topic, byte* payload, unsigned int length) {
  
    int i = 0;

  for(i=0; i<length; i++) {
    message_buff[i] = payload[i];
  }
  message_buff[i] = '\0';
  
  String msgString = String(message_buff);
  //Serial.println("Payload: " + msgString);
  Serial.println(msgString);
  
}

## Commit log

2015-11-26 Updated hardware files kicad
    [matrix.kicad_pcb, matrix.sch]
2016-01-05 Wifi and PSU added
    [Starling WiPSU ver_0.1.kicad_pcb, Starling WiPSU ver_0.1.sch]
2016-01-30 Wifi and PSU ver0.1 updated
    [Starling WiPSU ver_0.1-B_Cu.gbr, Starling WiPSU ver_0.1-B_Mask.gbr, Starling WiPSU ver_0.1-B_SilkS.gbr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]
2016-01-30 Added Design Files
    [Starling Five.dxf, Starling ONE.dxf, Starling TEN.dxf]
2016-01-30 added PCB and Code
    [Starling_V1.kicad_pcb, Starling_V1.sch, Starling_V1.stl]
2016-02-09 Sorted the structure
    Arranged all the files accordingly, do pull from here and maintain the
    structure
    [Starling Five.dxf, Starling ONE.dxf, Starling TEN.dxf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]
2016-02-29 Wifi BO added
    [Starling WiPSU ver_0.1.kicad_pcb, Starling WiPSU ver_0.1.sch]
